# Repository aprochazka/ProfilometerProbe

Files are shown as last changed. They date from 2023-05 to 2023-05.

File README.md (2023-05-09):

# Profilometer Probe
## Device was created as part of a bachelor's thesis at BUT VUT 2022/2023 named Probe for Determining the Surface Condition of Small Diameter Barrels 
## Detailed description of device design and implementation is inside thesis  

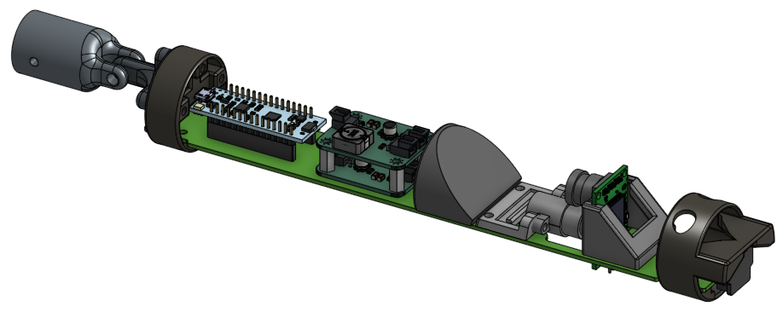
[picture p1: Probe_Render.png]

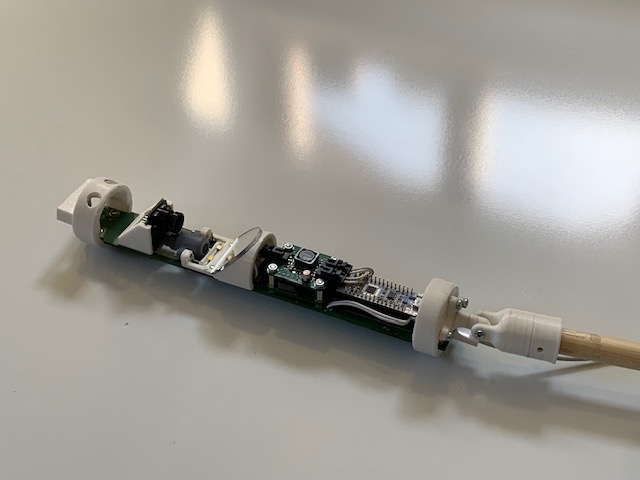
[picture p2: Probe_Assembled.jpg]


## Hardware

### Models

- All 3D printable models are located inside Models folder
- Models are designed to be printed with standard 2mm layer height
- When slicing be sure to print outer walls first to make print more accurate

### Assembly 

- All screws are size M3
- Assembly should be done accordingly  

### PCB

- PCB should be two sided with 1.6mm width
- Design files are created in KiCad

### Components

- Development board: Nucleo L432KC
- Camera: ArduCam mini 5MP Plus
- Distance sensor: Pimoroni LV53L1X
- Complete list of components and connectors for probe can be found inside HW/Parts.md

## Firmware for profilometer probe

### Build

- Build using Makefile inside Firmware folder (dependency: arm-none-eabi)
- Flash onto hardware using flash option for make command `$ make flash`

### Usage

- Connect probe to pc using usb c cable and firmware will start sending sending data automatically

### Documentation

- Create documentation using 'doc' option of Makefile '$ make doc' 

## Software for receiving data

### Build

- Build using Makefile inside Receiver folder

### Usage

- Has to be run with sudo permissions to correctly access USB CDC port.
- '$ sudo ./main -p <name of the port> [-s Save received jpeg to files] [-r Print raw received CDC data to standard output]'
- Prefer running with optional -s command for ability to inspect already captured images 

### Documentation

- Create documentation using 'doc' option of Makefile '$ make doc' 

### TODO

- Process image and filter only laser line from it
- Use precessed data to determine depth or height of irregularities

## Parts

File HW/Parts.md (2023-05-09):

# Parts:

## Lighting
##### 2x bxfn-40g-11l-3c3-3

## Distance Sensor 
##### Pimoroni VL53L1X

## USB
##### USB C

## Camera 
##### ArduCam Mini 5MP Plus

## All connectors are 2.54mm pin sockets

## Resistors for USB
##### 5.1 kOhm

## Resistor for bridge between RST and 3V3 pin
##### 60 Ohm

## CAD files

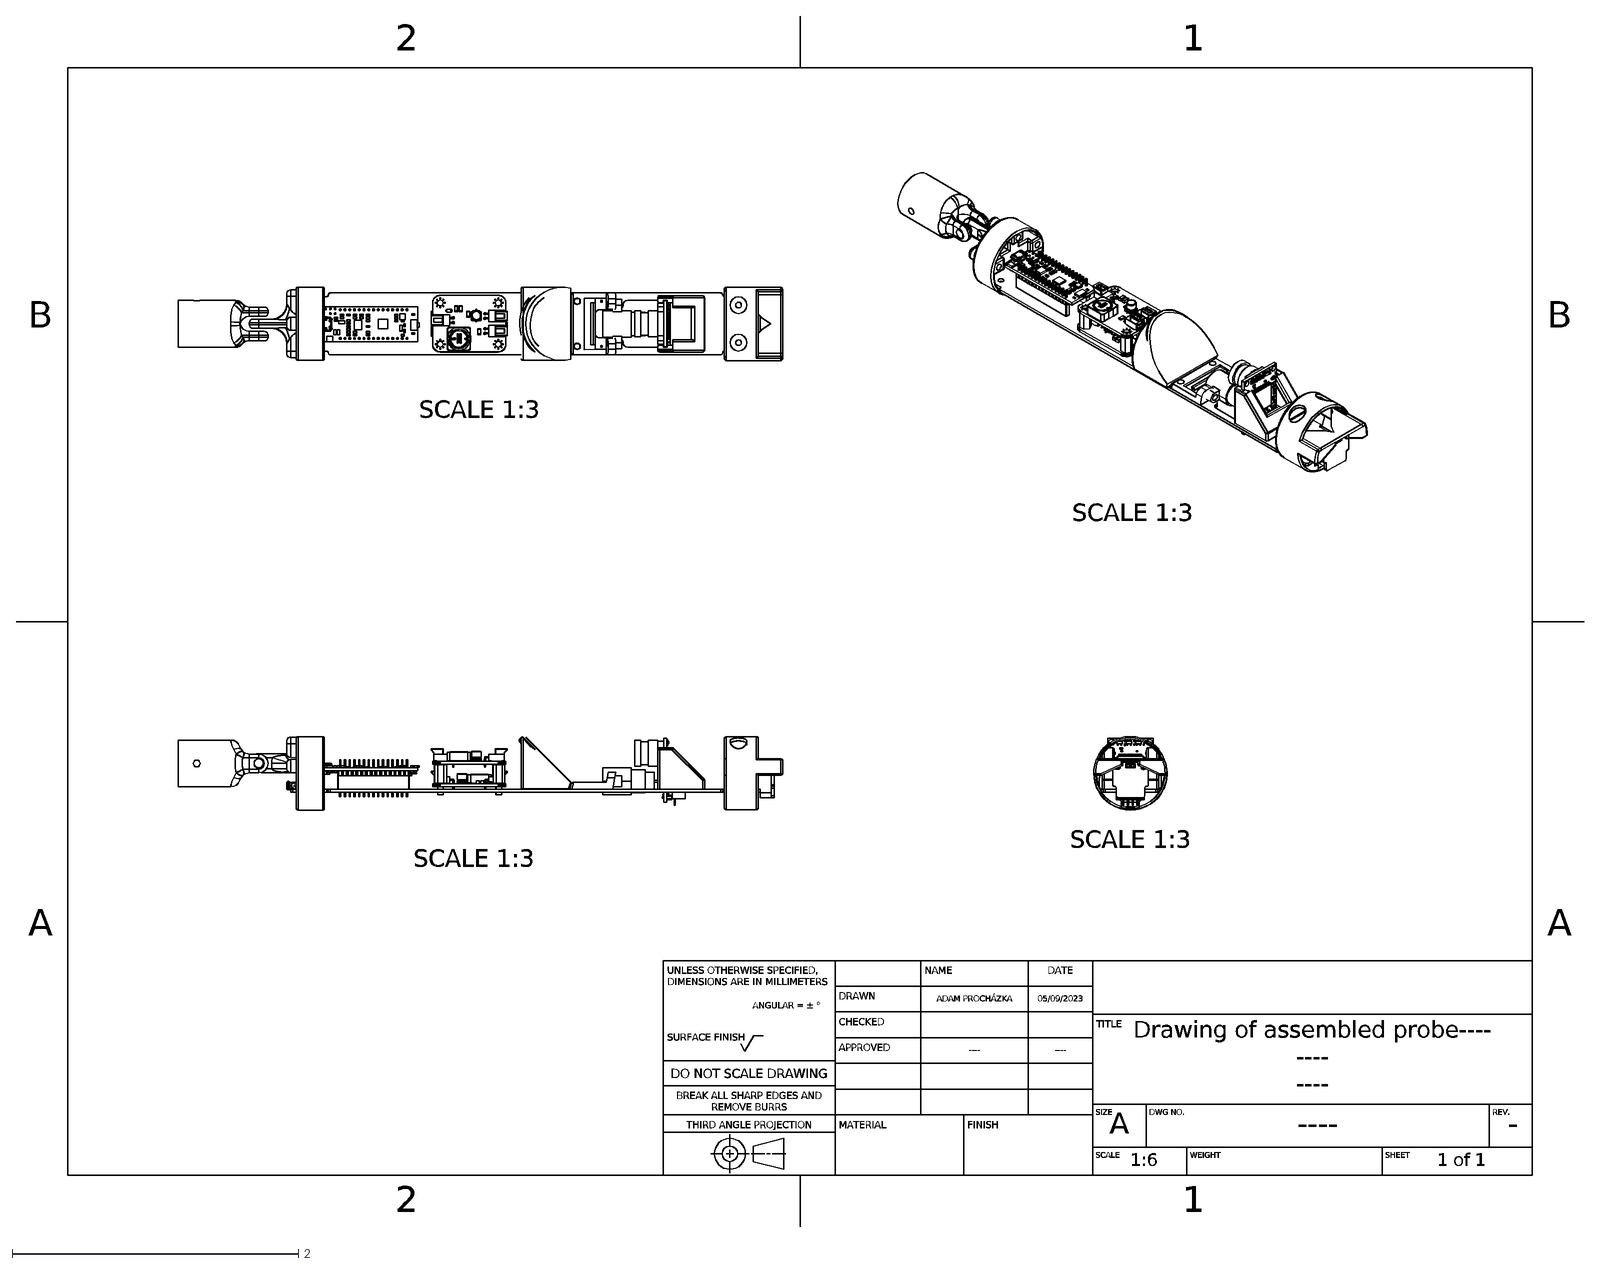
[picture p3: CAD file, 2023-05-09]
Models/Assembly Drawing.dxf
2
1
A
B
UNLESS OTHERWISE SPECIFIED, DIMENSIONS ARE IN MILLIMETERS
ANGULAR = ± °
SURFACE FINISH
DO NOT SCALE DRAWING
BREAK ALL SHARP EDGES AND REMOVE BURRS
THIRD ANGLE PROJECTION
NAME
DATE
DRAWN
ADAM PROCHÁZKA
05/09/2023
CHECKED
APPROVED
----
MATERIAL
FINISH
TITLE
Drawing of assembled probe----
SIZE
DWG NO.
REV.
-
SCALE
1:6
WEIGHT
SHEET
1 of 1
SCALE 1:3

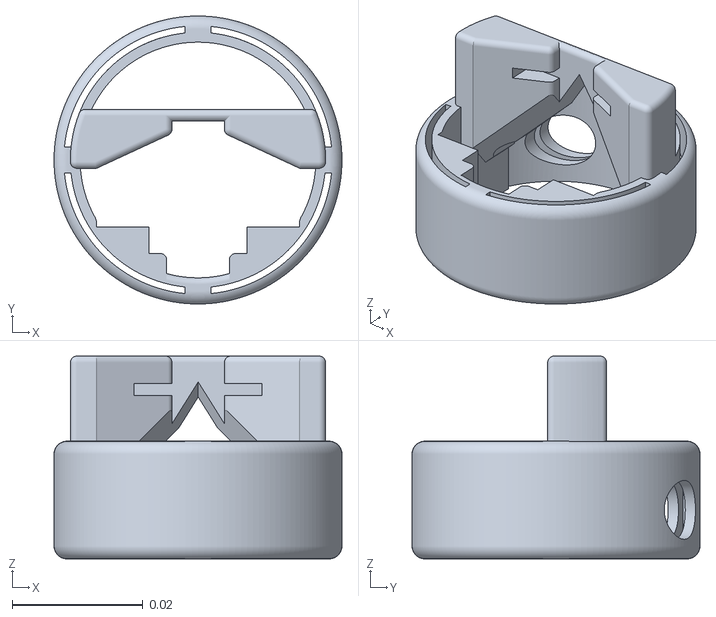
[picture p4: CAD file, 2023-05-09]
Models/Support_Ring_Back_Extended.stl
0.044 x 0.044 x 0.031

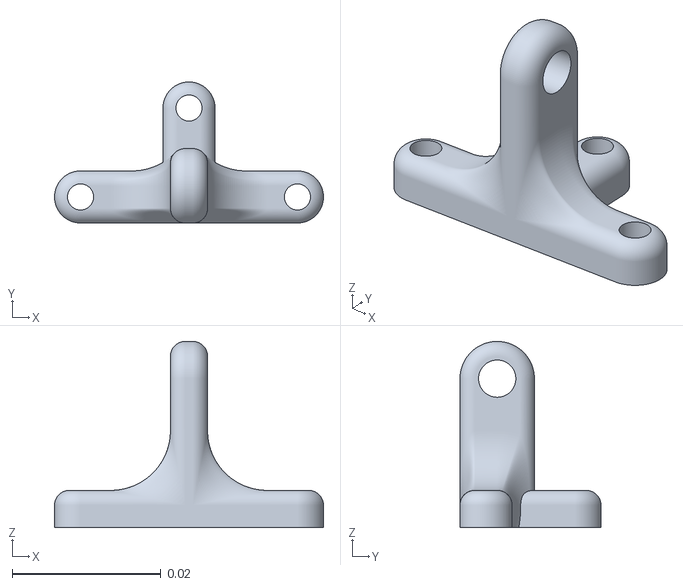
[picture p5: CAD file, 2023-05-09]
Models/Handle_Probe_Side.stl
0.0361 x 0.0189 x 0.025

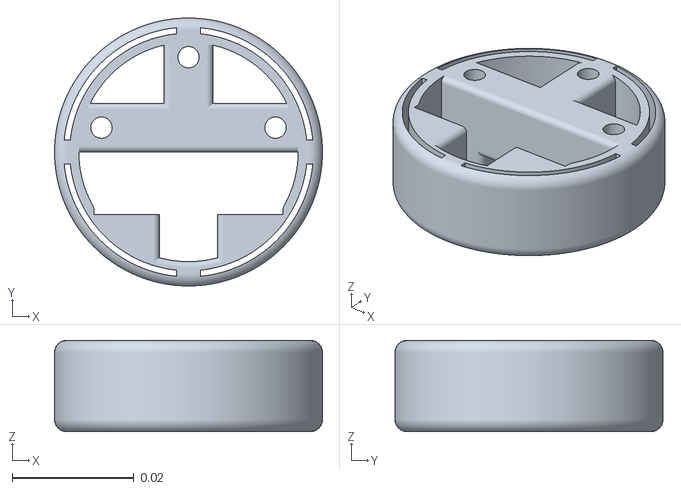
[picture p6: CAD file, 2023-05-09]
Models/Support_Ring_Front_Extended.stl
0.044 x 0.044 x 0.015

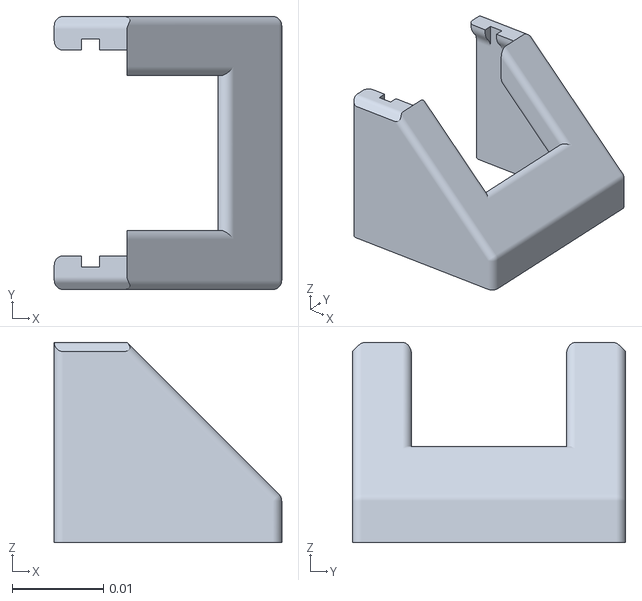
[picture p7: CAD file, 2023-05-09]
Models/Camera_Support.stl
0.025 x 0.03 x 0.022

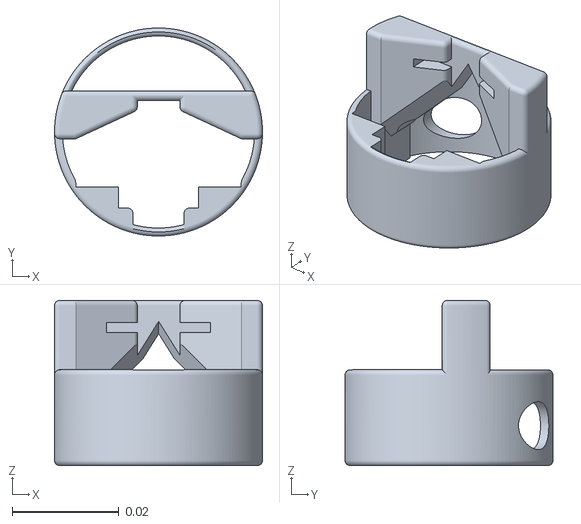
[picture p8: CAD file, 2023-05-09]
Models/Support_Ring_Back.stl
0.039 x 0.039 x 0.031

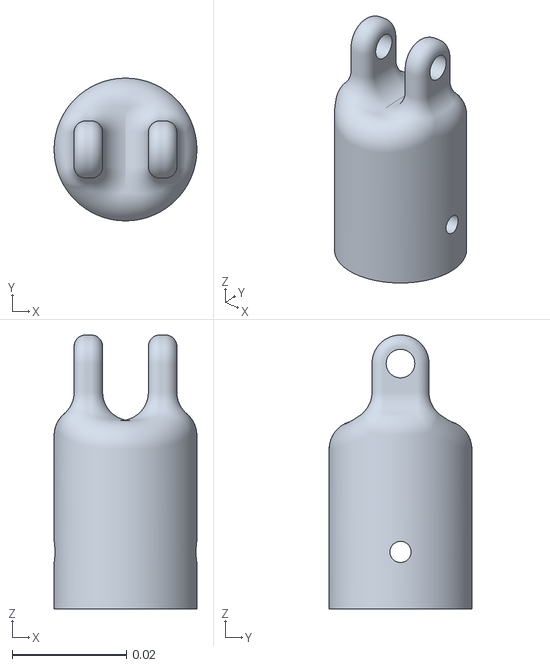
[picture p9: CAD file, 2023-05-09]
Models/Handle_Stick_Side.stl
0.025 x 0.025 x 0.048

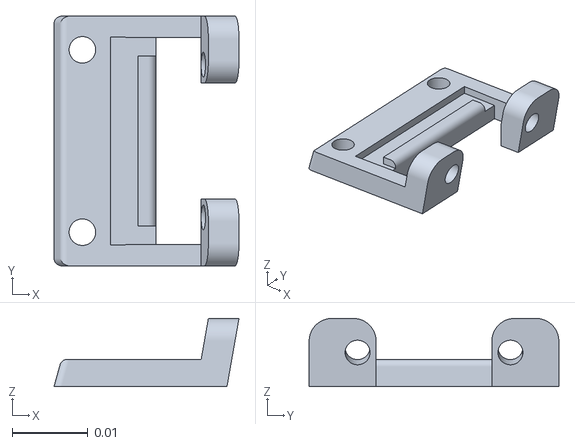
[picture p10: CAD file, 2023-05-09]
Models/LED_Laser.stl
0.0245 x 0.033 x 0.009

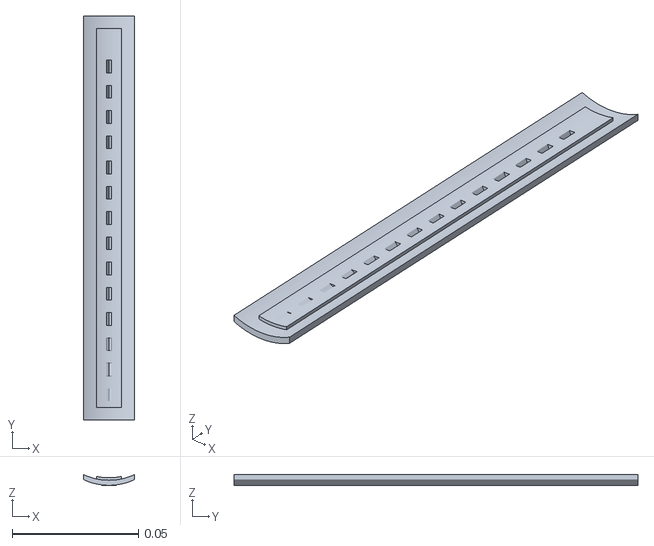
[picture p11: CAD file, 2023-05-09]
Models/Test_Module.stl
0.02 x 0.16 x 0.00421

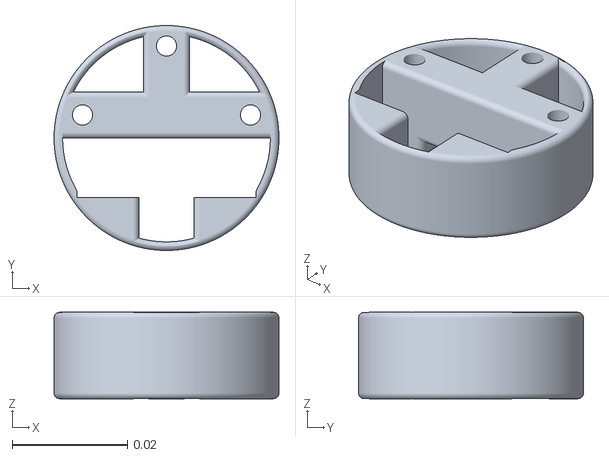
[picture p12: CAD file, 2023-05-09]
Models/Support_Ring_Front.stl
0.039 x 0.039 x 0.015

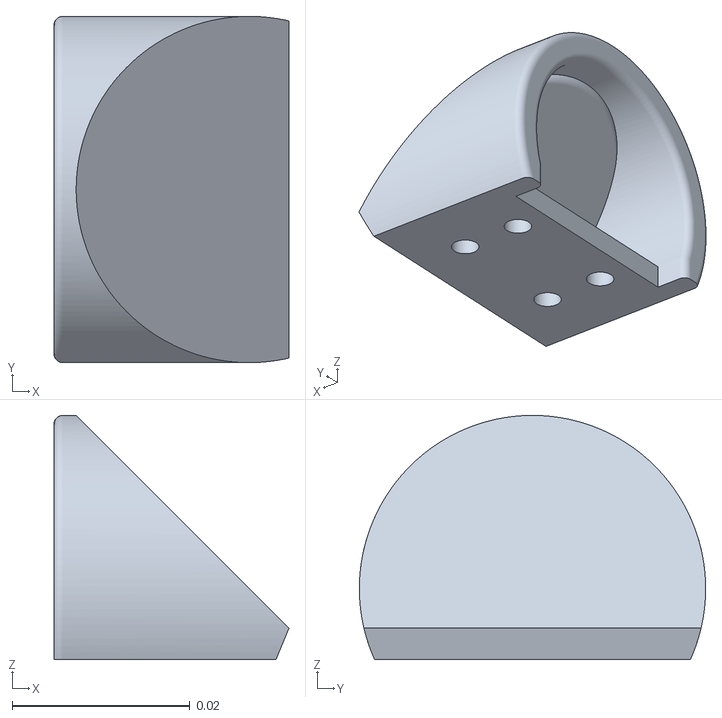
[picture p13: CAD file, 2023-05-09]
Models/Mirror_Support.stl
0.0265 x 0.039 x 0.0275

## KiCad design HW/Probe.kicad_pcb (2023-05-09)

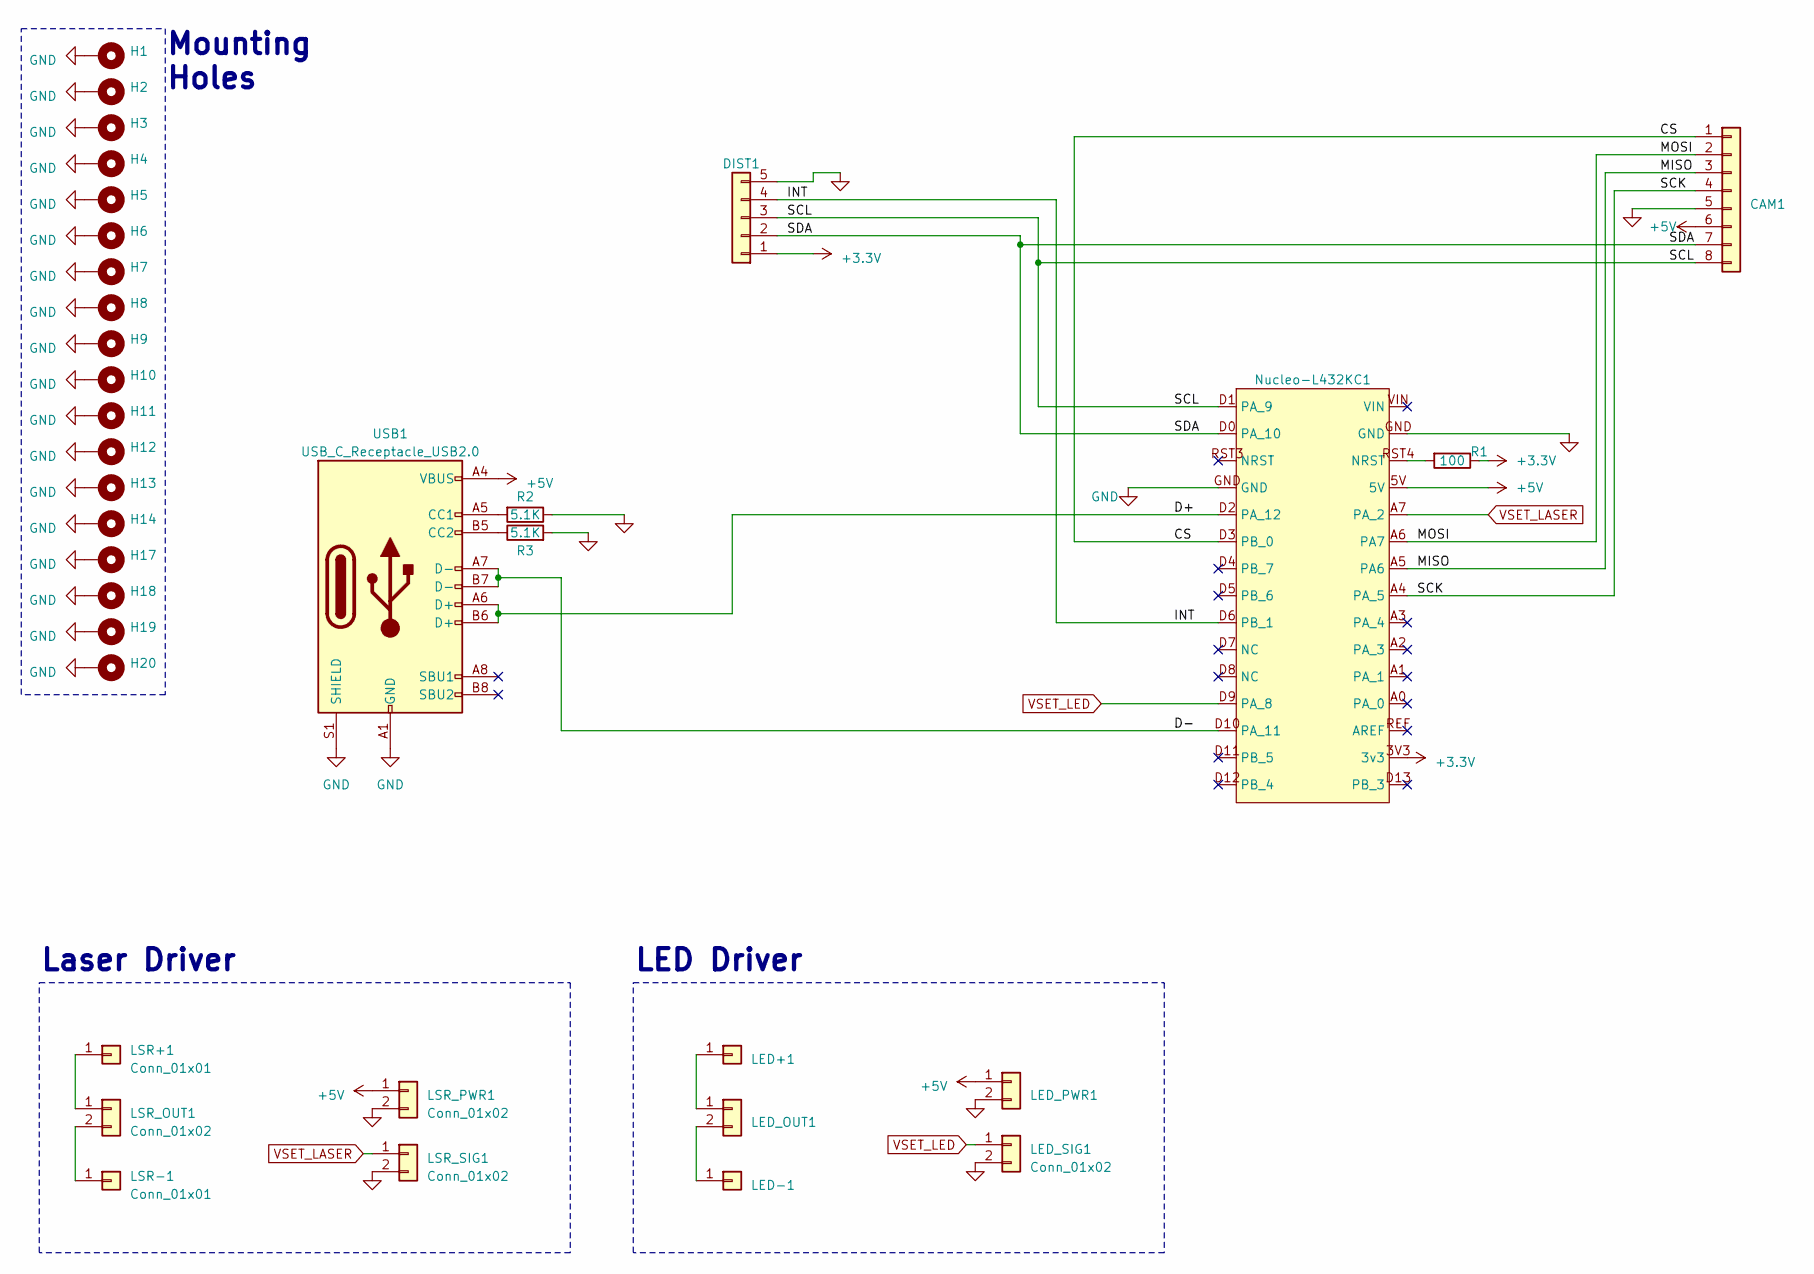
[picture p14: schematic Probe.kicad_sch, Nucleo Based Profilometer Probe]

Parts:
CAM1: Conn_01x08; PinSocket_1x08_P2.54mm_Vertical
DIST1: Conn_01x05; PinSocket_1x05_P2.54mm_Vertical
H1, H2, H3, H4, H5, H6, H7, H8, H9, H10, H11, H12, H13, H14, H17, H18, H19, H20: MountingHole_Pad; MountingHole_3.2mm_M3_Pad_Via
LED+1: Conn_01x01; PinHeader_1x01_P2.54mm_Vertical
LED-1: Conn_01x01; PinHeader_1x01_P2.54mm_Vertical
LED_OUT1: Conn_01x02; PinHeader_1x02_P2.54mm_Vertical
LED_PWR1: Conn_01x02; PinHeader_1x02_P2.54mm_Vertical
LED_SIG1: Conn_01x02; PinHeader_1x02_P2.54mm_Vertical
LSR+1: Conn_01x01; PinHeader_1x01_P2.54mm_Vertical
LSR-1: Conn_01x01; PinHeader_1x01_P2.54mm_Vertical
LSR_OUT1: Conn_01x02; PinHeader_1x02_P2.54mm_Vertical
LSR_PWR1: Conn_01x02; PinHeader_1x02_P2.54mm_Vertical
LSR_SIG1: Conn_01x02; PinHeader_1x02_P2.54mm_Vertical
Nucleo-L432KC1: MODULE_NUCLEO-L432KC
R1: 100; R_0603_1608Metric
R2, R3: 5.1K; R_0603_1608Metric
USB1: USB_C_Receptacle_USB2.0; USB_C_Receptacle_HRO_TYPE-C-31-M-12

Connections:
+3.3V: DIST1.1, Nucleo-L432KC1.3V3 (3v3), R1.1
+5V: CAM1.6, LED_PWR1.1, LSR_PWR1.1, Nucleo-L432KC1.5V, USB1.A4 (VBUS), USB1.A9 (VBUS), USB1.B4 (VBUS), USB1.B9 (VBUS)
/CS: CAM1.1, Nucleo-L432KC1.D3 (PB_0)
/D+: Nucleo-L432KC1.D2 (PA_12), USB1.A6 (D+), USB1.B6 (D+)
/D-: Nucleo-L432KC1.D10 (PA_11), USB1.A7 (D-), USB1.B7 (D-)
/INT: DIST1.4, Nucleo-L432KC1.D6 (PB_1)
/MISO: CAM1.3, Nucleo-L432KC1.A5 (PA6)
/MOSI: CAM1.2, Nucleo-L432KC1.A6 (PA7)
/SCK: CAM1.4, Nucleo-L432KC1.A4 (PA_5)
/SCL: CAM1.8, DIST1.3, Nucleo-L432KC1.D1 (PA_9)
/SDA: CAM1.7, DIST1.2, Nucleo-L432KC1.D0 (PA_10)
GND: CAM1.5, DIST1.5, H1.1, H2.1, H3.1, H4.1, H5.1, H6.1, H7.1, H8.1, H9.1, H10.1, H11.1, H12.1, H13.1, H14.1, H17.1, H18.1, H19.1, H20.1, LED_PWR1.2, LED_SIG1.2, LSR_PWR1.2, LSR_SIG1.2, Nucleo-L432KC1.GND, R2.1, R3.2, USB1.A1 (GND), USB1.A12 (GND), USB1.B1 (GND), USB1.B12 (GND), USB1.S1 (SHIELD)
unnamed: LED+1.1, LED_OUT1.1
unnamed: LED-1.1, LED_OUT1.2
unnamed: LSR+1.1, LSR_OUT1.1
unnamed: LSR-1.1, LSR_OUT1.2
unnamed: Nucleo-L432KC1.RST4 (NRST), R1.2
unnamed: R2.2, USB1.A5 (CC1)
unnamed: R3.1, USB1.B5 (CC2)
VSET_LASER: LSR_SIG1.1, Nucleo-L432KC1.A7 (PA_2)
VSET_LED: LED_SIG1.1, Nucleo-L432KC1.D9 (PA_8)

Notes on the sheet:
Laser Driver
Mounting Holes
LED Driver

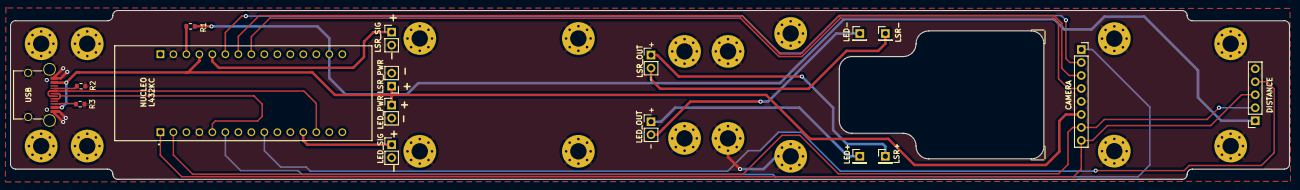
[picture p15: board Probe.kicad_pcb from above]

Board: 2 copper layers, 250.0 x 33.0 mm, 35 parts (0 on the bottom side), 21 nets.

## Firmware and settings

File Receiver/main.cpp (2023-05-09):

/**
 * @file main.cpp
 * @brief Source file for the main application.
 * @author Adam Prochazka <xproch0f>
 *
 * This file contains the implementation of the main application, which integrates the Receiver
 * and Displayer classes, manages their threads, and handles the overall execution flow.
 */

#include "main.hpp"
#include "Receiver.hpp"

#ifndef DISPLAYER_HPP
#include "Displayer.hpp"
#endif

int cdcFile;
bool quit = false;
/**
* @brief Reads and processes data from the serial communication in a loop. - for debug purposes
* @param receiverPtr Pointer to a pointer to the Receiver class instance.
* @param port Serial port to be opened.
*/
void readLoop(Receiver ** receiverPtr, char * port){
    (*receiverPtr)->openStream(port);
    (*receiverPtr)->initSerial();

    while (!quit) {
        unsigned char character[CDC_FRAME_SIZE];
        (*receiverPtr)->readCdcData(&character);
        if((*receiverPtr)->findStart(&character) != -1)
        {std::cout << "start" << std::endl;}
        else if((*receiverPtr)->findEnd(&character) != -1)
        {std::cout << "stop" << std::endl;}
        else{
          std::cout << "-"; 
        }
        std::this_thread::sleep_for(std::chrono::milliseconds(3));
    }

    close(cdcFile);
}

/**
* @brief Flips through the textures in a separate thread.
* @param displayerPtr Pointer to the Displayer class instance.
*/
void windowFlipThread(Displayer * displayerPtr){
  displayerPtr->flipThroughTextures();
}

/**
* @brief Wrapper function to call bufferToDisplay() method of the Receiver instance.
* @param receiverPtr Pointer to a pointer to the Receiver instance.
*/
void WrapperBufferToDisplay(Receiver ** receiverPtr){
  (*receiverPtr)->bufferToDisplay();
}

/**
 * @brief Main loop for the Receiver instance.
 * @param receiverPtr Pointer to a pointer to the Receiver instance.
 */
void receiverLoop(Receiver ** receiverPtr, bool *q, bool printRaw, bool saveToFile){
  std::vector<std::thread> displayThreads;
  while(!(*q)){

    (*receiverPtr)->fillBuffer(saveToFile);
    (*receiverPtr)->bufferToDisplay(printRaw);

    //running in a thread also works, but for simplicity is not used. 
    //std::thread t2(WrapperBufferToDisplay, receiverPtr);
    //t2.detach();
  }
}

int main(int argc, char * argv[])
{
  
  char * port = nullptr;
  bool printRaw = false;
  bool saveToFile = false;

  int opt;
  while ((opt = getopt(argc, argv, "p:r:s")) != -1) {
      switch (opt) {
          case 'p':
              port = optarg;
              break;
          case 'r':
              printRaw = true;
              break;
          case 's':
              saveToFile = true;
              break;
          default:
              std::cerr << "Usage: sudo ./main -p <serial_port> [-r to print raw data] [-s to save images]" << std::endl;
              std::cerr << "Example: sudo ./main -p /dev/ttyACM0 -r -s" << std::endl;
              return 1;
      }
  }

  if (!port) {
      std::cerr << "Serial port not specified" << std::endl;
      return 1;
  }

  std::cout << "Serial port: " << port << std::endl;
  std::cout << "Print raw data: " << (printRaw ? "true" : "false") << std::endl;
  std::cout << "Save images: " << (saveToFile ? "true" : "false") << std::endl;

  Displayer dis;
  Receiver *rec = new Receiver(&dis);

  
  dis.createWindow();
  dis.renderWindow();

  rec->openStream(port);
  rec->initSerial();
  
  rec->initTextures();

  rec->fillBuffer();
  rec->bufferToDisplay();

  std::thread t1(receiverLoop, &rec, &quit, std::ref(printRaw), std::ref(saveToFile));
  t1.detach();

  dis.windowLoop(&quit);

  rec->closeStream();

  return 0;
}

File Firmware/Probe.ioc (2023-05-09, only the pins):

Mcu.UserName=STM32L432KCUx
PA0.GPIO_Label=MCO [High speed clock in]
PA0.Signal=RCC_CK_IN
PA1.GPIO_Label=DEBUG_LED
PA1.Signal=GPIO_Output
PA10.Signal=I2C1_SDA
PA11.Signal=USB_DM
PA12.Signal=USB_DP
PA2.Signal=S_TIM15_CH1
PA5.Signal=SPI1_SCK
PA6.Signal=SPI1_MISO
PA7.Signal=SPI1_MOSI
PA8.GPIO_Label=VSET_LED
PA8.Signal=GPIO_Output
PA9.Signal=I2C1_SCL
PB0.GPIO_Label=CHIP_SELECT
PB0.Signal=GPIO_Output

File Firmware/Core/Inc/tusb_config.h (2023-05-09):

/**
 ******************************************************************************
 * @file           : tusb_config.h
 * @brief          : Configuration file for USB communication.
 * @author         : Adam Prochazka <xproch0f>
 ******************************************************************************
 
 * @attention
 *
 * File was from the large part taken from the TinyUSB repository and just slightly configured for projects usecase. 
 * Original file contains this disclaimer:
 * 
 * The MIT License (MIT)
 *
 * Copyright (c) 2019 Ha Thach (tinyusb.org)
 *
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
 */

#ifndef _TUSB_CONFIG_H_
#define _TUSB_CONFIG_H_

#ifdef __cplusplus
 extern "C" {
#endif

//--------------------------------------------------------------------+
// Board Specific Configuration
//--------------------------------------------------------------------+

// RHPort number used for device can be defined by board.mk, default to port 0
#ifndef BOARD_TUD_RHPORT
#define BOARD_TUD_RHPORT      0
#endif

// RHPort max operational speed can defined by board.mk
#ifndef BOARD_TUD_MAX_SPEED
#define BOARD_TUD_MAX_SPEED   OPT_MODE_DEFAULT_SPEED
#endif

//--------------------------------------------------------------------
// COMMON CONFIGURATION
//--------------------------------------------------------------------
#define CFG_TUSB_MCU                 OPT_MCU_STM32L4
#define CFG_TUSB_OS                  OPT_OS_NONE
#define BOARD_DEVICE_RHPORT_SPEED    OPT_MODE_DEFAULT_SPEED
#define BOARD_DEVICE_RHPORT_NUM      0
#define CFG_TUSB_RHPORT_MODE         (OPT_MODE_DEVICE | OPT_MODE_DEFAULT_SPEED)

// defined by board.mk
#ifndef CFG_TUSB_MCU
#error CFG_TUSB_MCU must be defined
#endif

#ifndef CFG_TUSB_OS
#define CFG_TUSB_OS           OPT_OS_NONE
#endif

#ifndef CFG_TUSB_DEBUG
#define CFG_TUSB_DEBUG        0
#endif

// Enable Device stack
#define CFG_TUD_ENABLED       1

// Default is max speed that hardware controller could support with on-chip PHY
#define CFG_TUD_MAX_SPEED     BOARD_TUD_MAX_SPEED

/* USB DMA on some MCUs can only access a specific SRAM region with restriction on alignment.
 * Tinyusb use follows macros to declare transferring memory so that they can be put
 * into those specific section.
 * e.g
 * - CFG_TUSB_MEM SECTION : __attribute__ (( section(".usb_ram") ))
 * - CFG_TUSB_MEM_ALIGN   : __attribute__ ((aligned(4)))
 */
#ifndef CFG_TUSB_MEM_SECTION
#define CFG_TUSB_MEM_SECTION
#endif

#ifndef CFG_TUSB_MEM_ALIGN
#define CFG_TUSB_MEM_ALIGN          __attribute__ ((aligned(4)))
#endif

//--------------------------------------------------------------------
// DEVICE CONFIGURATION
//--------------------------------------------------------------------

#ifndef CFG_TUD_ENDPOINT0_SIZE
#define CFG_TUD_ENDPOINT0_SIZE    64
#endif

//------------- CLASS -------------//
#define CFG_TUD_CDC               1
#define CFG_TUD_MSC               0
#define CFG_TUD_HID               0
#define CFG_TUD_MIDI              0
#define CFG_TUD_VENDOR            0

// CDC FIFO size of TX and RX
#define CFG_TUD_CDC_RX_BUFSIZE   (TUD_OPT_HIGH_SPEED ? 512 : 64)
#define CFG_TUD_CDC_TX_BUFSIZE   (TUD_OPT_HIGH_SPEED ? 512 : 64)

// CDC Endpoint transfer buffer size, more is faster
#define CFG_TUD_CDC_EP_BUFSIZE   (TUD_OPT_HIGH_SPEED ? 512 : 64)

#ifdef __cplusplus
 }
#endif

#endif /* _TUSB_CONFIG_H_ */

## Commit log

2023-02-23 Error in makefile
    [wch-riscv.cfg]
2023-03-02 Move TinyUSB to root and try to implement cdc_msc
    [wch-riscv.cfg]
2023-03-22 add block scheme of device
2023-03-24 add block scheme of device to readme
2023-04-04 Camera progress
2023-04-06 Sending pictures - problems with cdc testing using receiver app
    [main.cpp]
2023-04-07 First fully working camera capture, transfer and receive!
2023-04-16 Add distance sensor, README update in next commit
2023-04-18 Create probe pcb
    [Camera.kicad_sch, Controller.kicad_sch, Probe.kicad_pcb]
2023-04-18 Update footprints for cam and distance sensor
    [Probe.kicad_pcb]
2023-04-19 Update PCB
    [Probe.kicad_pcb, Probe.kicad_sch]
2023-04-19 Add title to sheets
    [Probe.kicad_pcb, Probe.kicad_sch]
2023-04-20 Change USB footprint, label PCB
    [Probe.kicad_pcb, Probe.kicad_sch]
2023-05-09 Push local changes for complete and functioning probe
    [Probe.kicad_pcb]
2023-05-09 Add stl files of device
    [Camera_Support.stl, Handle_Probe_Side.stl, Handle_Stick_Side.stl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]
2023-05-09 Update parts
    [Assembly Drawing.dxf]
